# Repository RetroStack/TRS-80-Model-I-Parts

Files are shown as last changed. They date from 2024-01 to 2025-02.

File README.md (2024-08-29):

# TRS-80 Model 1 - Parts

This project includes various items that were part of a TRS-80 Model 1 and have been replicated for 3D printing. Over time, things get lost or break, and this repository was created to provide a way to recover these lost items. The entire project is available under the MIT license.

Below is a list of available items, each with a link to a more detailed description and the STL file. If there is an item missing that you need, see the note at the end of this file.

## Main Enclosure

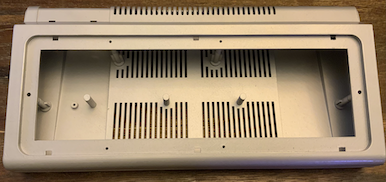
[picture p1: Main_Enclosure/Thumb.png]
Main Enclosure


## Main Enclosure Panel

Main Enclosure Panel

## PCB Stand-Off

PCB Stand-Off

## Keyboard

### Stem (ALPS)

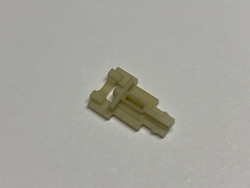
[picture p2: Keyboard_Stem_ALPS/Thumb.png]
Keyboard Stem for ALPS


### Spacebar Clip

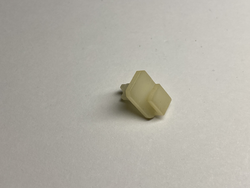
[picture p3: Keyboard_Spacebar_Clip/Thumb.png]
Keyboard Spacebar Clip


### Keyboard Clip

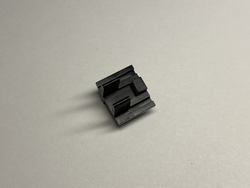
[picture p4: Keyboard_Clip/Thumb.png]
Keyboard Clip


### LED Stand-off

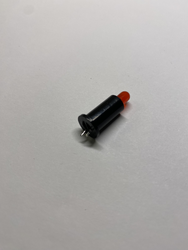
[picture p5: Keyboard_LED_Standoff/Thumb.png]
Keyboard LED Stand-Off


### Button Placeholder (Enter)

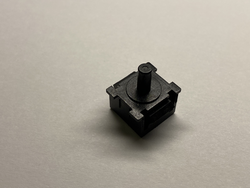
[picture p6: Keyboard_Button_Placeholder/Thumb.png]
Keyboard Button Placeholder (Enter)


### Shield

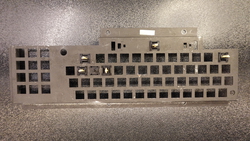
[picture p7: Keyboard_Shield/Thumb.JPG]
Keyboard Shield


### Bezel

Keyboard Bezel

## Extension Interface

### Cover (Medium)

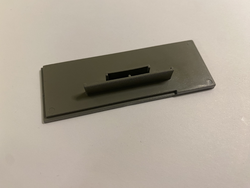
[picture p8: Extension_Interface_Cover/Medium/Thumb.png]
Extension Interface Cover - Medium Size


NOTE: There are three types of covers used: small, medium, and large. I only have the medium, and therefore, only that was digitized.

## External Links

- [Thingiverse - Expansion Interface Port Cover](https://www.thingiverse.com/thing:3330282)
- [Thingiverse - Various port covers](https://www.thingiverse.com/thing:3925677)
- [Thingiverse - Expansion Interface Power Supply Cover](https://www.thingiverse.com/thing:6117675)
- [Thingiverse - Power Supply Case](https://www.thingiverse.com/thing:6273822)
- [Thingiverse - Expansion Interface PCB Case](https://www.thingiverse.com/thing:5742225)
- [Thingiverse - Replacement Screw Post](https://www.thingiverse.com/thing:3202410)
- [Thingiverse - Keyboard Spacer](https://www.thingiverse.com/thing:3764548)
- [Thingiverse - Screw Standoffs Plate](https://www.thingiverse.com/thing:3010034)
- [Thingiverse - Level II Upgrade PCB Mount](https://www.thingiverse.com/thing:3252566)

- [Thingiverse - Mini Model 1](https://www.thingiverse.com/thing:3155677)
- [Thingiverse - Mini Model 2](https://www.thingiverse.com/thing:3497435)
- [Thingiverse - Mini Model 3](https://www.thingiverse.com/thing:4476778)

## Missing Item?

Is an item you are looking for missing in this repo? Feel free to suggest this item to be digitized on my Patreon page (see below).

## Main TRS-80 Model 1 Repository

For additional resources related to the TRS-80 Model 1, be sure to check out the central page for the TRS-80 Model 1 on RetroStack. You can find it [here](https://www.github.com/RetroStack/TRS-80-Model-I).

## Support this Project

RetroStack is passionate about exploring and preserving the legacy of older computer systems. My work involves creating detailed documentation and videos to share the knowledge. I am also dedicated to reviving these classic systems by reimplementing them and offering replacement parts at no cost. If you're keen on supporting this unique project, I invite you to visit my [Patreon page](https://www.patreon.com/RetroStack). Your support would be immensely valuable and greatly appreciated!

## License

This project is licensed under the MIT License - see the [LICENSE](LICENSE) file for details.

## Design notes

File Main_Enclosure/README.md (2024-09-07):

# TRS-80 Model 1 - Main Enclosure - 3D Printer

This page provides three different versions of the TRS-80 Model 1 main enclosure:

- The original, replicating the original case as closely as possible.
- The improved, a main enclosure still compatible with the original but with a few enhancements.
- A mini version for Raspberry Pi emulators.

The first two cases are compatible with the original, fitting nicely on top of each other, and the top and bottom parts can replace broken parts of the original case.

Here is a comparison of a painted replica to an original case:

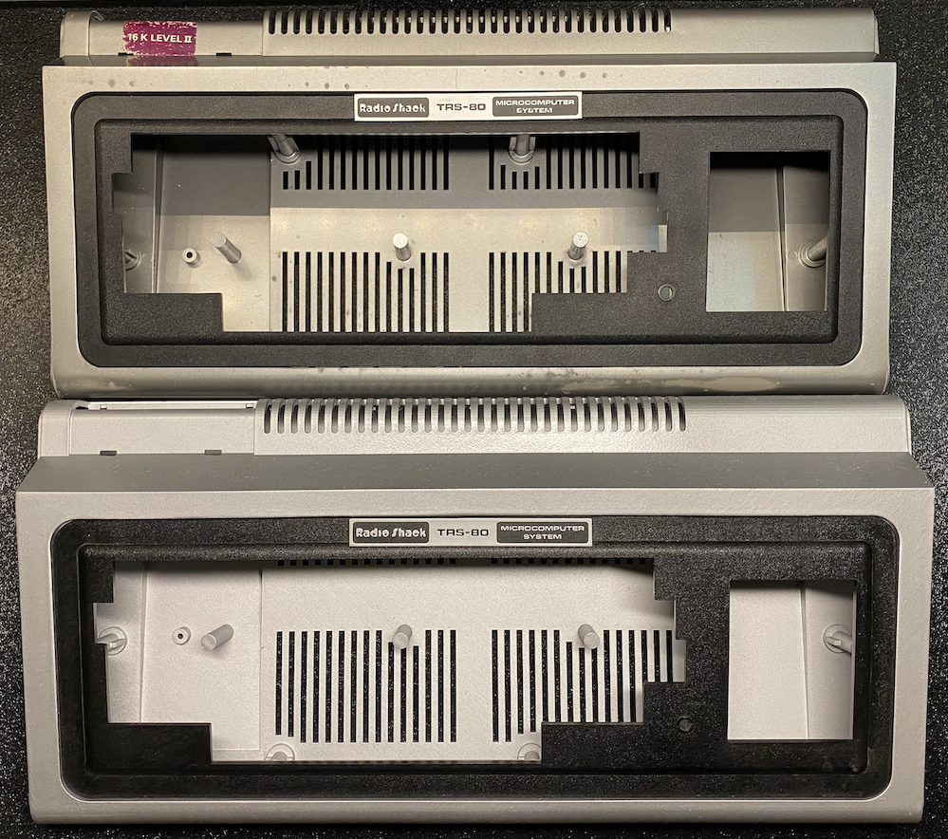
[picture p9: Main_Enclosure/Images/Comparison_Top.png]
Top

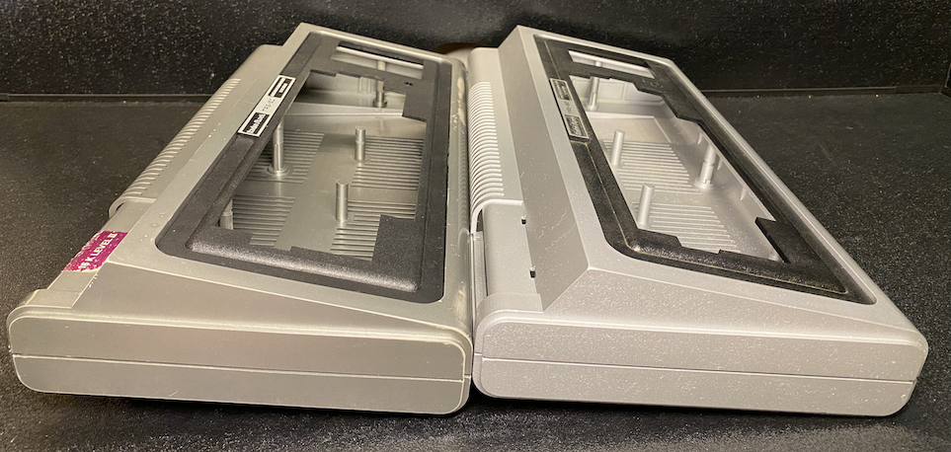
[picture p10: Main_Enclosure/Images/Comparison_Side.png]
Side

Bottom

## The Original

A fully painted case after printing:
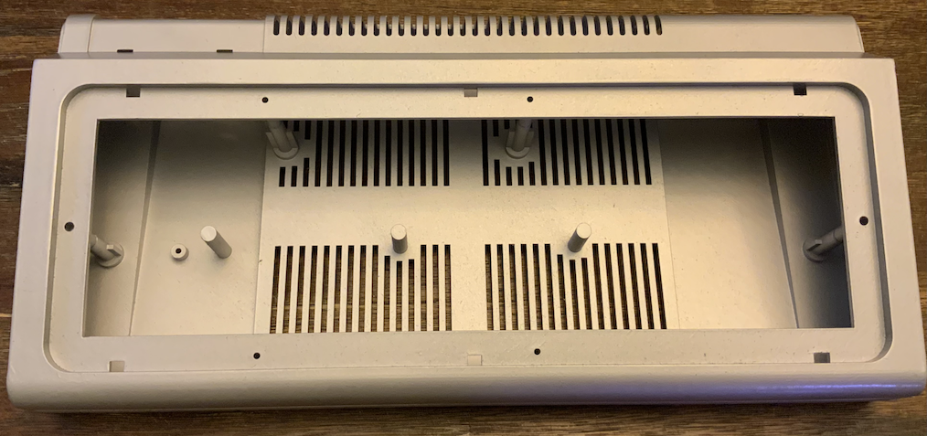
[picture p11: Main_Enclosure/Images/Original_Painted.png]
Original Painted


A cross-section of the case:
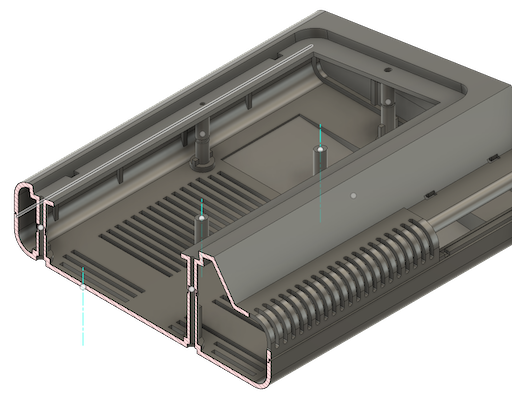
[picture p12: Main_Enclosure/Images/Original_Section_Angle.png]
Original Cross Section


There are two versions of this:

- A full STL of both the upper and lower parts
- A split version with parts no larger than 216mm x 205mm to fit many home 3D printers (scroll down)

### STL

The following files are available in STL format:

- [STL (Top)](Original_Top.stl)
- [STL (Bottom)](Original_Bottom.stl)

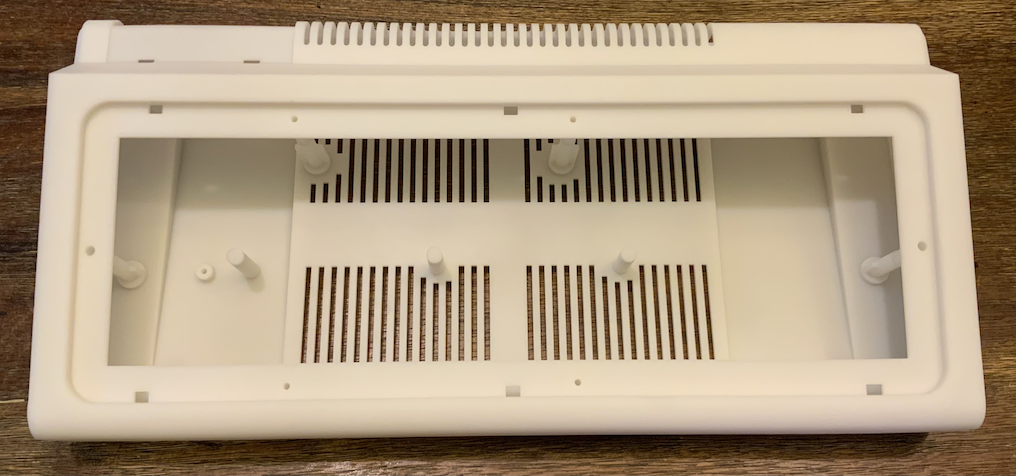
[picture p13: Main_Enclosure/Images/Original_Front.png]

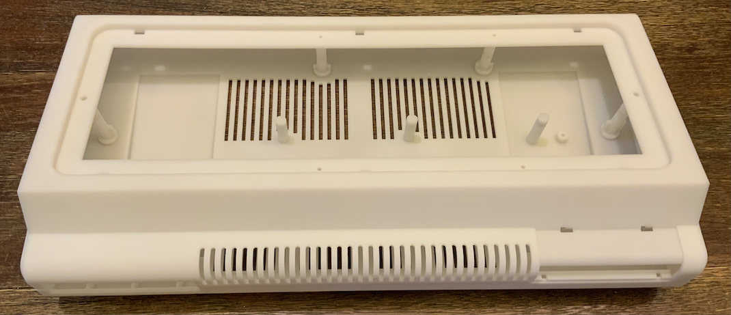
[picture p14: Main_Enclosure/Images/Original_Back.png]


### Print Instructions

You can print them yourself, but most likely you do not have such a large printer. You can order them online. What follows are instructions for JLC3DP, which I've had good experiences with. Additionally, they take care of sanding and finishing.

- Go to [JLC3DP](https://www.jlcpcb.com).
- Click the "Quote Now" button under the "3D Printing" image.
- Click the "Add 3D file" and select the STL file provided above.

A few options appear. I always selected "SLA(Resin)" for the technology, which has a very smooth surface.

The default selection of "LEDO 6060 Resin" is what I've used for the case. It is also the more affortable option.

Leave all other options as-is.

You still have to select a "Product Description". Apparently, this is some customs requirement. I've selected "Office Appliances and Accessories" and "Keyboard Enclosure" in the past.

You can then hit "Save to Cart" and checkout.

By default, they will review your designs and send you an email to pay within a few hours. Simply go back to your order page (after you've created an account) and select "Pay".

NOTE: Most of the time, however, they will also send you an email to confirm that you want to assume the risk of ordering the design as-is as they are too long and may deform during production or have parts which are too thin. I've always accepted the risk and never had any trouble.

### 3D Printer friendly STL

This 3D printer-friendly version of the file is divided into parts no larger than 216mm x 205mm. Each part can be clipped into the other. Additionally, there is a small gap available for glue to permanently affix the case parts together.

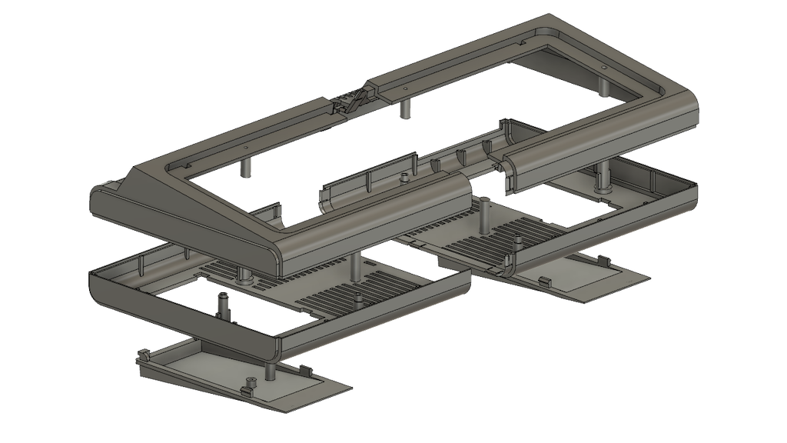
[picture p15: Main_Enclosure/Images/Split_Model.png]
Split Case


- [STL (Top-Left)](Top_Left.stl)
- [STL (Bottom-Left)](Bottom_Left.stl)
- [STL (Bottom-Left-Foot)](Bottom_Left_Foot.stl)
- [STL (Top-Right)](Top_Right.stl)
- [STL (Bottom-Right)](Bottom_Right.stl)
- [STL (Bottom-Right-Foot)](Bottom_Right_Foot.stl)

#### Case Parts

The top and bottom are split, and each side can be clipped into the other.

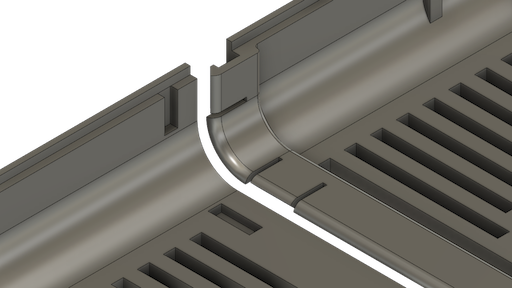
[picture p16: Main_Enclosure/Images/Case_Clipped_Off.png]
Unclipped Case

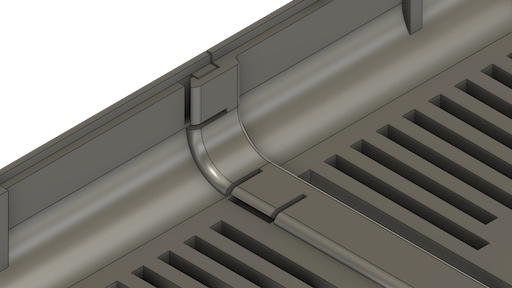
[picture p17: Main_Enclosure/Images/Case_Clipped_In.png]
Clipped Case


#### Foot Parts

The feet can be clipped in by pivoting them into place and then clipping in the other side. Separating the feet will reduce unnecessary support.

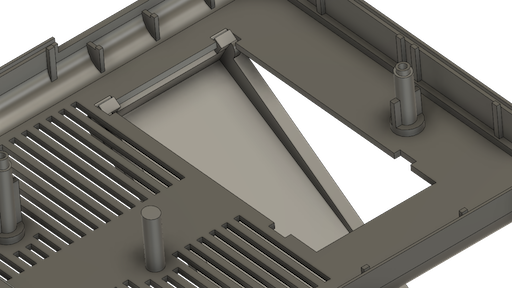
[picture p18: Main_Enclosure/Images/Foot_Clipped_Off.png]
Unclipped Foot

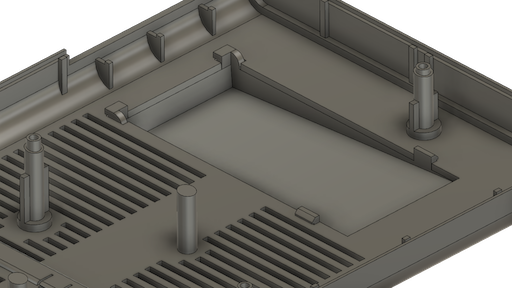
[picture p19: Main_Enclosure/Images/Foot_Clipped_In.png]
Clipped Foot


The top and bottom halves can be screwed together like the original case. 

## The Improved

A fully painted case after printing:
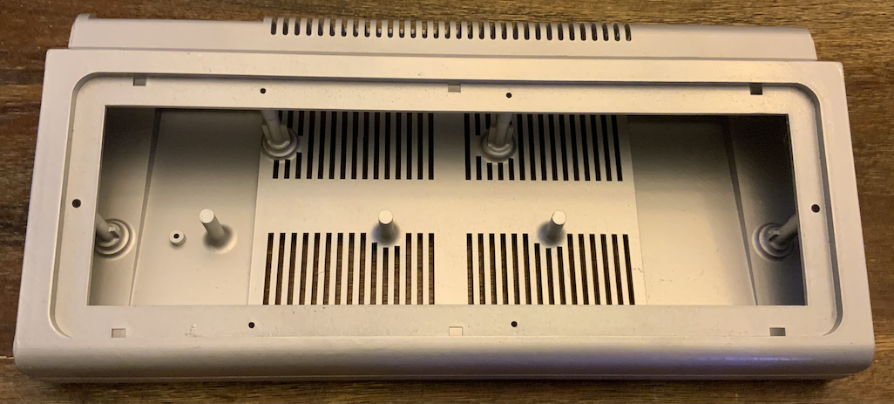
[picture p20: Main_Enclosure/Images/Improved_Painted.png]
Improved Painted


A cross-section of the case:
Original Cross Section

### Differences to Original

There are a few differences.

To help show these differences, here is a cross-section of the original and the improved versions:
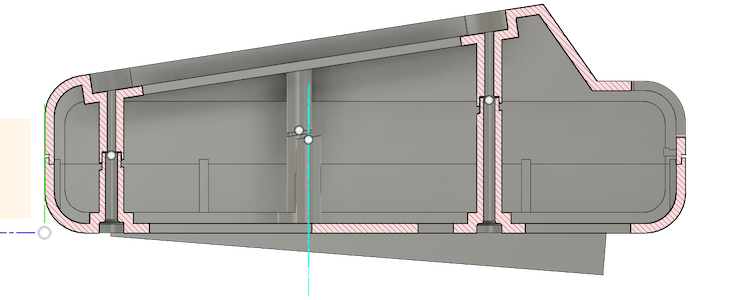
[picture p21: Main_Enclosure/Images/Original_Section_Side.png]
Original

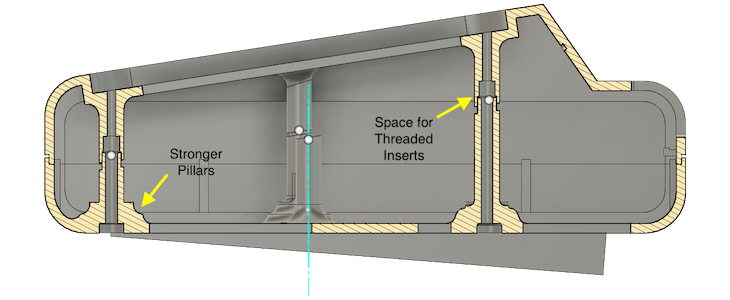
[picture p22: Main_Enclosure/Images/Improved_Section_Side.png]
Improved


The internal pillars that hold the PCB and keyboard in place, and their additional function of keeping the case together through screws, easily break off in the original. The new improved version has a much wider base to avoid breaking at the base of these pillars, addressing a common issue for the top and bottom of the case.

After opening the case a few times, the threads created by the self-threading screws in the old plastic are stripped and won't hold the case together anymore. To avoid this problem altogether, the improved case now has the (optional) ability to add knurled threaded inserts.

There are additional changes:

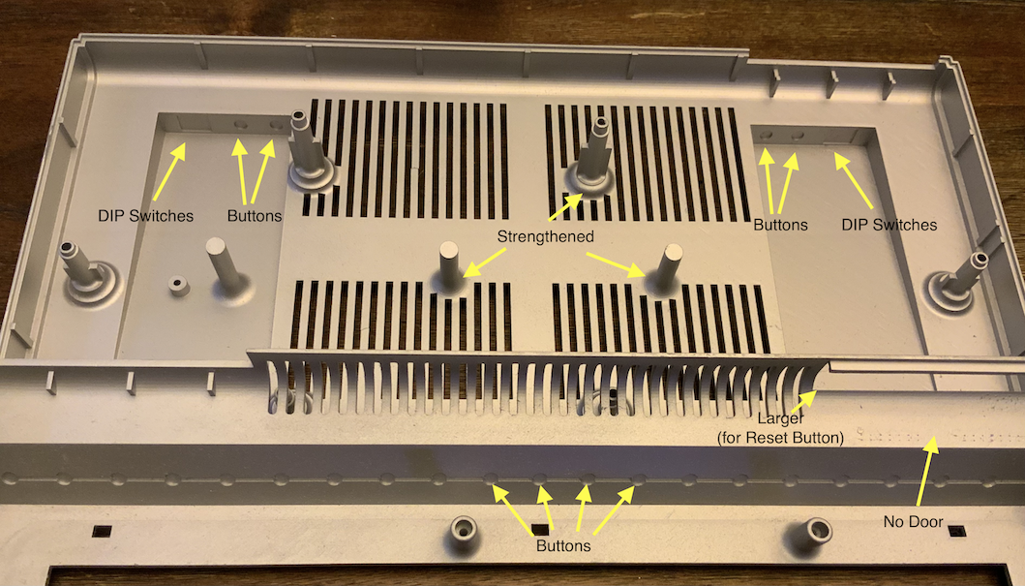
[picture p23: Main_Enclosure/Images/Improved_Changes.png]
Changes


- Provides perforated areas for DIP switches, potentiometers, and buttons in the top and base of the case.
- The opening in the back has been slightly enlarged to make it easier to access the reset button.
- The door on the back, which is missing in nearly all cases nowadays, was completely removed.

Many of these improvements were suggested by various people, including Amar, Scott, and Ven.

### STL

The following files are available in STL format:

- [STL (Top)](Improved_Top.stl)
- [STL (Bottom)](Improved_Bottom.stl)

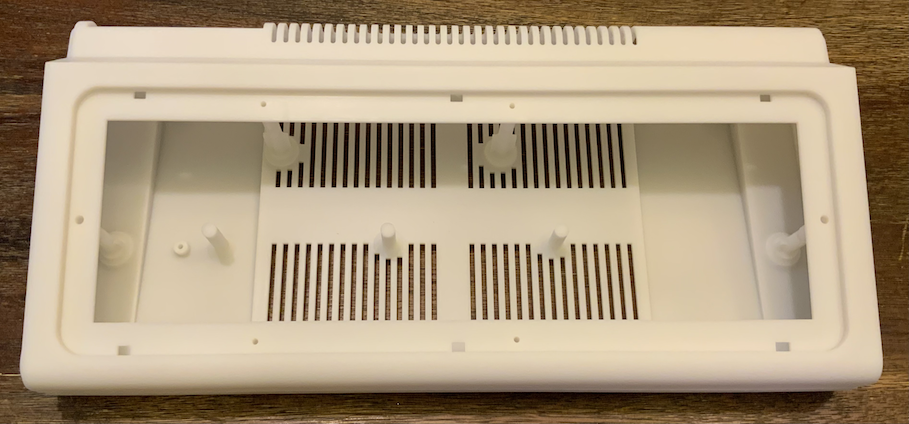
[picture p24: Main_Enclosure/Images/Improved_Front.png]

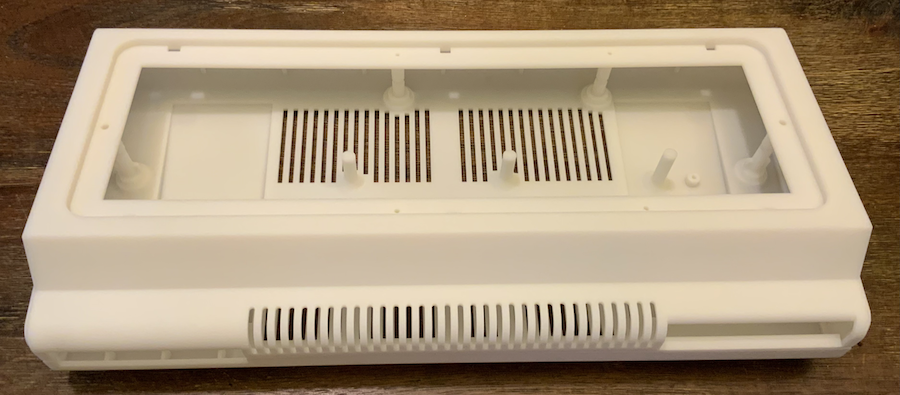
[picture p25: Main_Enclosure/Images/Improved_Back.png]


### Print Instructions

Use the same print instructions as the original case above.

## Mini Case

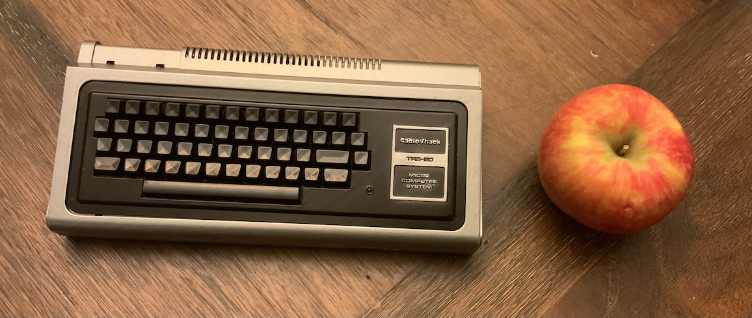
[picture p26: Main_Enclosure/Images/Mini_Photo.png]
Model 1 Mini


A compact version designed to hold an emulator without cluttering your desk space can be appealing to some. This case is specifically tailored for Raspberry Pi emulators. It features convenient front access to the SD card and a widened opening at the back, where the edge connector would typically be, allowing easy access to all USB ports.

The case is compatible with Raspberry Pi version 1-3 and Raspberry Pi W. It is not compatible with the latest version 4.

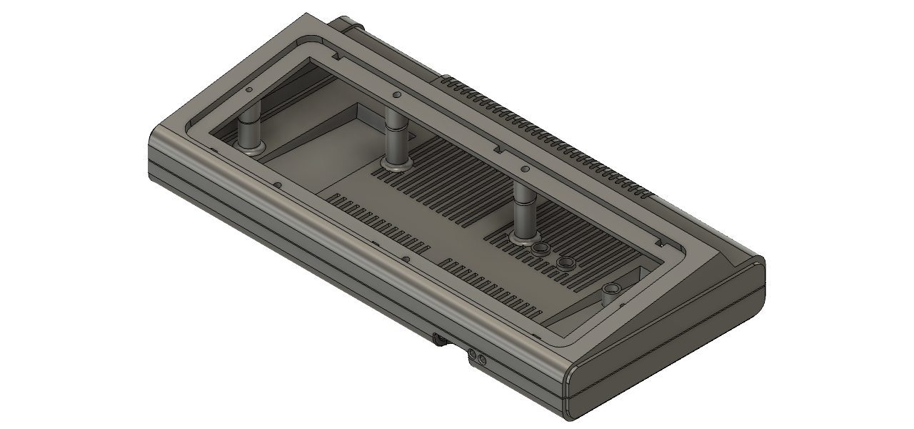
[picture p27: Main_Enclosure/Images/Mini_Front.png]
Model 1 Mini

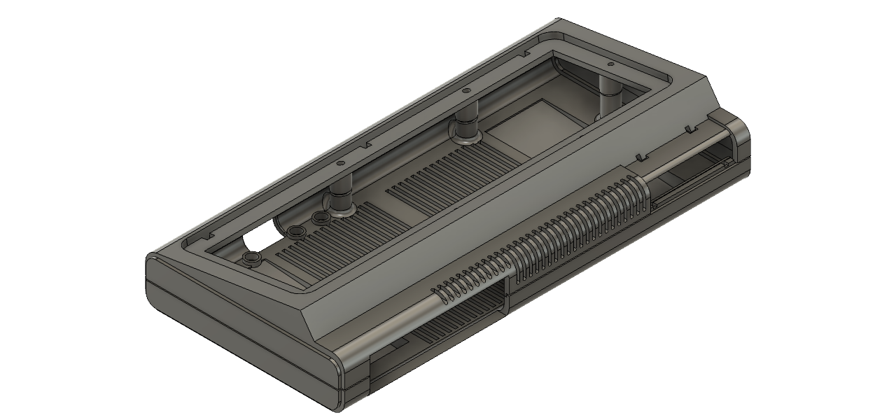
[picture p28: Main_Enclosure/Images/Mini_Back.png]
Model 1 Mini

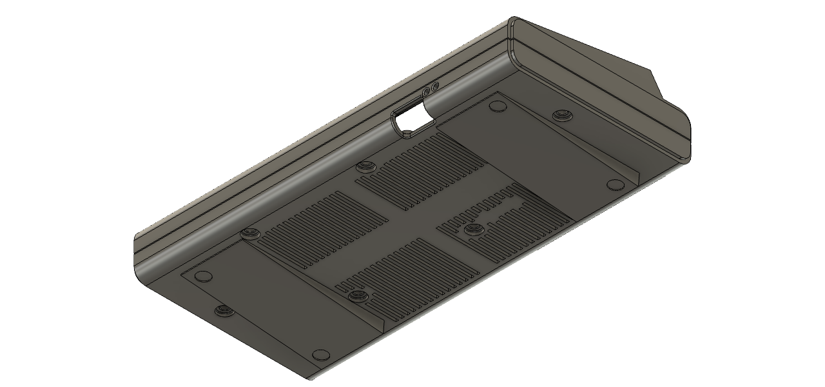
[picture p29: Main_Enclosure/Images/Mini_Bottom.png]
Model 1 Mini


Here is a quick comparison of the sizes of all three cases mentioned on this page:

Size Comparison

The case also includes a custom Bezel that emulates the original keyboard:

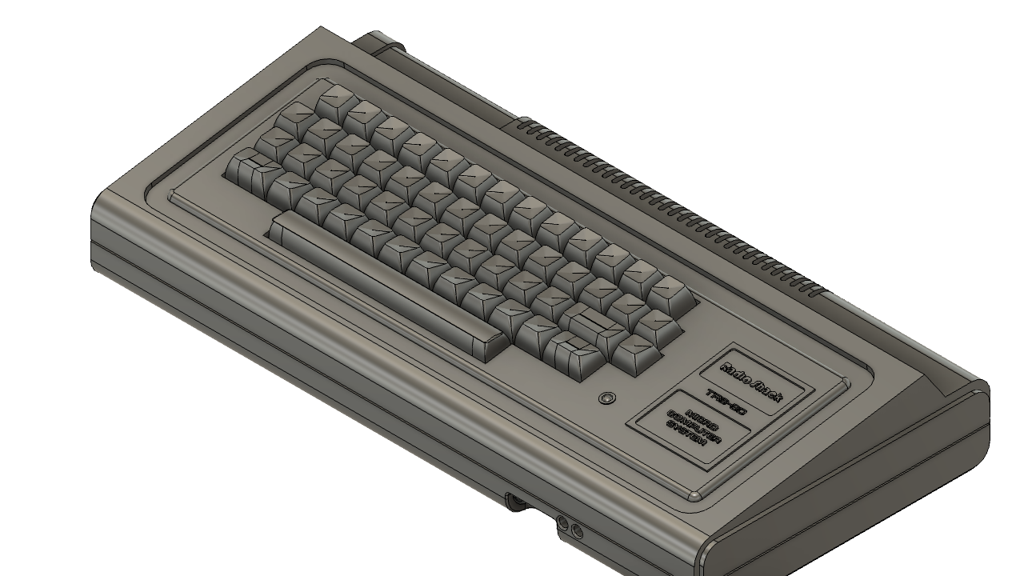
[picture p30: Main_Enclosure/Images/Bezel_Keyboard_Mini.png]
Mini Bezel


### STL

- [STL (Top)](Top_Mini.stl)
- [STL (Bottom)](Bottom_Mini.stl)
- [STL (Bezel)](Bezel_Alpha_Original_Keys_Mini.stl)

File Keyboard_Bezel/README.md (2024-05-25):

# TRS-80 Model 1 - Keyboard Bezel

The keyboard bezel covers the keyboard and closes up the case in the front.

**NOTE**: If you are looking for the Bezels of the MX Keyboard with the smaller spacebar, then please go to the [MX Keyboard repo](https://github.com/RetroStack/TRS-80-Model-I-Keyboard-MX) instead.

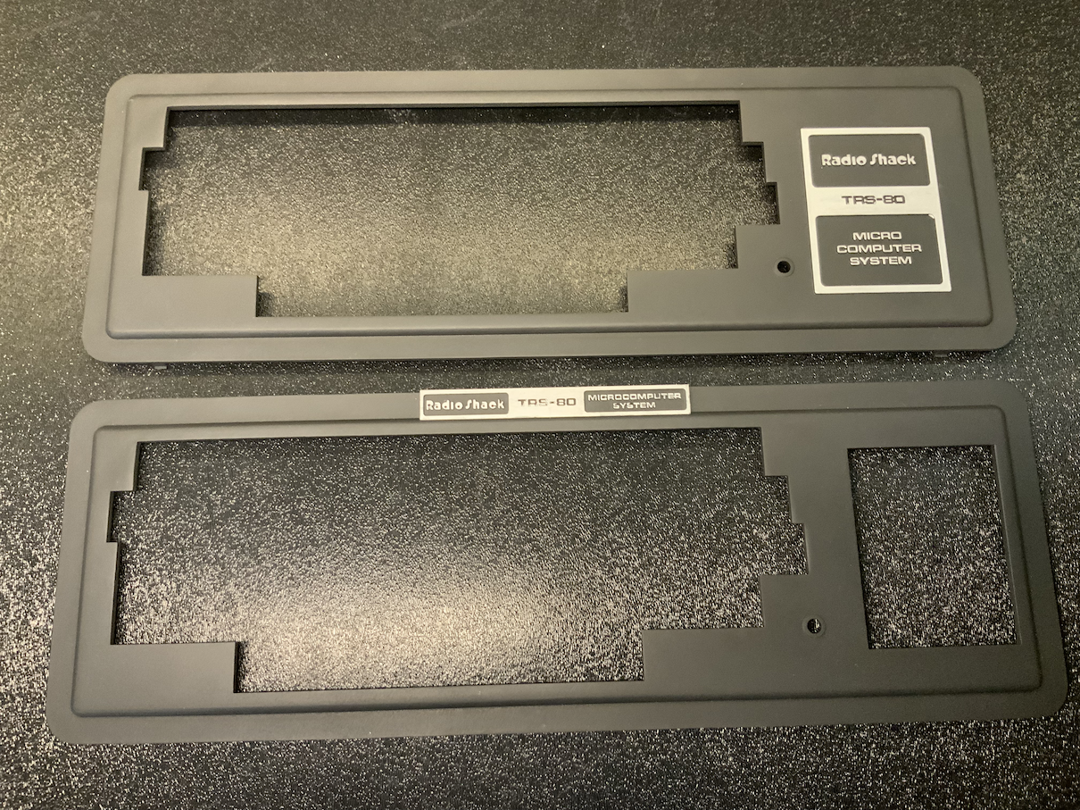
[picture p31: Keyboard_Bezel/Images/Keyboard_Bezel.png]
View


## STL

Following designs are available in STL format:

- [Full keyboard with Numpad](Bezel_NumPad_Original.stl)
- [Keyboard without the Numpad](Bezel_Alpha_Original.stl)

## Order Instruction - [JLC3DP](https://www.jlcpcb.com) (service of JLCPCB)

You can print them yourself, but most likely you do not have such a large printer. You can order them online. What follows are instructions for JLC3DP, which I've had good experiences with. Additionally, they take care of sanding and finishing.

- Go to [JLC3DP](https://www.jlcpcb.com).
- Click the "Quote Now" button under the "3D Printing" image.
- Click the "Add 3D file" and select the STL file provided above.

A few options appear. In either case, I always selected "SLA(Resin)" for the technology, which has a very smooth surface.

For the bezel, I would choose the "Black Resin" option. It is a bit more expensive than the default, but it will reduce post-processing for you as you probably do not want a white bezel.

Leave all other options as-is.

You still have to select a "Product Description". Apparently, this is some customs requirement. I've selected for both "Office Appliances and Accessories" and "Keyboard Enclosure".

You can then hit "Save to Cart" and checkout.

By default, they will review your designs and send you an email to pay within a few hours. Simply go back to your order page (after you've created an account) and select "Pay".

NOTE: Most of the time, however, they will also send you an email to confirm that you want to assume the risk of ordering the design as-is as they are too long and may deform during production or have parts which are too thin. I've always accepted the risk and never had any trouble.

## Use Cases

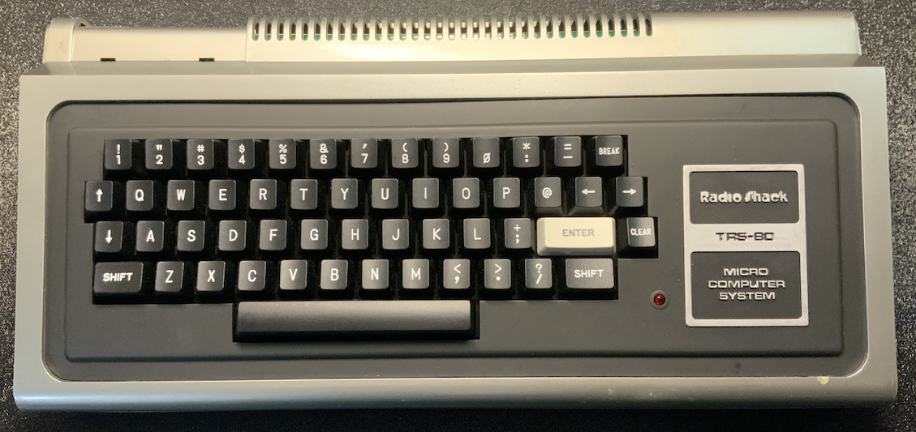
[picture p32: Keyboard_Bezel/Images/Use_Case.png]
Assembled


## Special STL

This special bezel can fill the hole of a broken keyboard, using a USB keyboard instead.

In STL format:

- [Keyboard Bezel](Bezel_Alpha_Original_Keys.stl)

Keyboard Bezel

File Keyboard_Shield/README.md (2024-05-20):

# TRS-80 Model 1 - Keyboard Shield (for ALPS Keyboard)

The keyboard shield has a few functions:

- Protects the keyboard PCB and mainboard PCB from external factors.
- Keeps the keycaps at a specified place and distance to the case.
- Separates the keyboard PCB from the main PCB

View 1
View 2

**NOTE**: If you are looking for the Shield of the MX Keyboard with the longer sides, then please go to the [MX Keyboard repo](https://github.com/RetroStack/TRS-80-Model-I-Keyboard-MX) instead.

## STEP

This is a sheet metal version of the keyboard shield replica. You can use the STEP file to submit it to online sheet metal fabs like SendCutSend, Fabworks, or PCBWay.

[STEP](Keyboard_Shield_ALPS_v2.step)

Configuration:

- Suggested Material: Steel G90 (SendCutSend), Steel 1008 (Fabworks)
- Thickness: 1.22mm (0.048")
- K Factor: 0.46
- Bend Radius: 0.762
- Finish: Matte Black

## Order Instructions - [Fabworks](https://www.fabworks.com)

Go to [Fabworks](https://www.fabworks.com) and drop the [STEP file](/Latest/TRS80_Model_I_Keyboard_MX_E2_Shield.step) into the upload section (or select it by clicking it).

This will open up a new page and show a small preview of the shield.

- Select the material "Steel 1008".
- Set thickness to 0.048" or 1.22mm.
- Select "Matte Black" as finish.
- (optionally) Modify the quantity

Click on "Checkout".

NOTE: The original shield has a thickness of 1.5mm. However, if you select 1.5mm and the paint of the finish is added, the thickness will increase, and the key switches won't fit anymore (or at least will not click in). Additionally, the design is for 1.22mm. Changing the thickness to another value will change the position of the mounting holes slightly. Small variations, however, should not be problematic.

## Use Cases

Top
Bottom

### Assembled

Top
Bottom

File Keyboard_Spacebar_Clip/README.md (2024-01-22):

# TRS-80 Model 1 - Keyboard Spacebar Clip - 3D Printer

The spacebar clip holds the small metal bar in place to ensure consistent pressure on the button across the spacebar keycap. It also helps to reduce pivoting, thereby decreasing the overall stress on the keycap pin. 

See the assembly instructions below.

Unfortunately, the metal rod is easily lost. Below is also a description of how to recreate the metal rod.

## STL

View 1
View 2

[STL](Keyboard_Spacebar_Clip.stl)

## 3D Printer-Friendly STL

View 1
View 2

[STL](Keyboard_Spacebar_Clip_Printable.stl)

### Print Instructions

- Lay the clip on either of its longer sides.
- Add support for the cross pin and the clip. The support at the cross pin will need to be removed afterward.

Print

## Use Cases

Uses

### Profile 

Bottom
Profile
Front
Side

### Assembled

Assembled

### Assembly

Step 1

1. Insert the cross pin on the back into either side of the spacebar keycap. Ensure you position the clip towards the top of the spacebar keycap, as the keycap is more slanted at the top than at the bottom.

Step 2

2. Press firmly on the largest flat areas of the clip on either side. Do not press on the clip itself, as it may crack from the pressure.

## Metal Rod

Rod

1. Cut a 1.6mm rod to a length of 152mm.
2. Make marks with a pencil on the rod on either side at 16mm and 10mm.
3. Bend one end of the rod at the 10mm mark 90 degrees, in any direction. Ideally, use a heavy-duty needle nose plier and bend just right before the mark. That way the bend will extend beyond the 10mm mark as expected with the measurement. The bend starts at 10mm.
4. Bend the next 90 degrees back in the same direction the rod was originally heading at the 16mm mark. Do the same as bfore: start bending it right before the mark.
5. Repeat steps 2 and 3 for the other side as well, but make sure the rod stays flat overall. The central part of the metal rod will have a length of about 120 mm.

**Note**: Ensure that the metal rod lies somewhat flat when placed on a table. You can twist the bends slightly to correct their direction, making them flat.

## Changelog

### 21st Jan 2024

- Updates to metal rod section: more accurate numbers and photo of result.
- Addition of chamfer to model to closely resemble original
- Addition of printable version: clip sides are flattened to read bed

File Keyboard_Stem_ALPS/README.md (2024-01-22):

# TRS-80 Model 1 - Keyboard Stem (for ALPS Keyboard) - 3D Printer

The stem transfers the force from a finger press on the keycap to the spring and simultaneously presses the metal flap inside the button, creating the contact needed for the button press to be recognized. These components easily break and often require replacement.

See the assembly and disassembly instructions below.

## STL

View 1
View 2

[STL](Keyboard_Stem_ALPS.stl)

## 3D Printer-Friendly STL

View 1
View 2

[STL](Keyboard_Stem_ALPS_Printable.stl)

### Print Instructions

- Lay the stem flat on the bed, ensuring the very flat side is at the bottom.
- Add support for the small pin for the spring. This support will need to be removed afterward for it to function properly.

Print

## Use Cases

Top
Bottom

### Assembled

Top
Bottom
Back

### Disassembled

Disassembled

### Disassembly

1. Use something thin and long that can go between the plastic flaps on each side of the casing. In this case, I've used an electronics tweezer. 

Step 1
Step 2

2. Push further in to spread the plastic flaps away from the bottom part of the case.

Step 3

3. Pull up on the top part of the case, separating the parts and freeing the stem. Be careful not to lose the spring, as it may shoot out during the process.

Step 4

### Assembly

Step 1

1. Insert the spring into the casing.
2. Pivot the casing forward so that the spring leans against the front of the casing.
3. Add the stem with the "pin" side down. The spring should be around the pin. Do not press down on the spring, as the stem will shoot out again as soon as you let go. Simply rest it on the spring.

Step 2

4. Get the top part of the cover. Make sure to orient the T-hole as shown.
5. Fit the stem through the hole and gently press together until the flaps click in.

Step 3

## Changelog

### 21st Jan 2024

- Thinning of stem: needed filing to not get stuck

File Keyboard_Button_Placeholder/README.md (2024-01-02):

# TRS-80 Model 1 - Keyboard Button Placeholder - 3D Printer

The placeholder is used to guide the Enter key straight down as the ALPS key is located on the other side of the 2x size key. Without it, the key will create too much strain on the Enter-key stem and break it.

See the assembly instructions below.

## STL

View 1
View 2

[STL](Keyboard_Button_Placeholder.stl)

## 3D Printer-Friendly STL

View 1
View 2

[STL](Keyboard_Button_Placeholder_Printable.stl)

### Print Instructions

- Lay the item on its side with the closed side of the box on the bed. The opening should be towards the top.
- Add support for the pin. This support will need to be removed afterward for it to function properly.

Print

**NOTE**: The real item has also clips, but it isn't necessary as the stem will keep this item in place.

## Use Cases

In Keyboard Shield
Keyboard Location

### Profile

Angle
Back
Side
Top

### Assembly

Location on the keyboard:

Location

Notice that the Enter Keycap has one side the has a round hole.

Step 1

The other side of the keycap will house the cross stem.

Step 2

With both fitted, it will look like the following. This is ony to demonstrate where each goes. Don't assemble already.

Step 3
Step 4

When the item is put into the shield, you can simply clip the keycap on top of it. This only works if the ALPS key is oriented correctly (see above image).

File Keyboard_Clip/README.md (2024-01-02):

# TRS-80 Model 1 - Keyboard Clip - 3D Printer

The clip is attached to the keyboard shield and holds the spacebar rod fixed to the keyboard shield. This is the counter part to the Keyboard Spacebar clips.

See the assembly and disassembly instructions below.

If you are missing the spacebar rod, then please check the instructions on how to create a new one in the Keyboard Spacebar clips page.

## STL

View 1
View 2

[STL](Keyboard_Clip.stl)

## 3D Printer-Friendly STL

View 1
View 2

[STL](Keyboard_Clip_Printable.stl)

### Print Instructions

- Lay the item on its side where the clip touches the bed. The two flaps should be on the top.
- Add support for the two flaps. This support will need to be removed afterwards to make sure the clip fits in the holes.

Print

## Use Cases

In Keyboard Shield
Removed from Shield
On Rod
Both on Rod

### Profile

Top
Top
Top
Top
Top
Top

### Assembled

Assembled

### Disassembly

Simply press the two flaps together and push it out. You can also use something small (round-ish) to push against the square plastic tab.

### Assembly

- Feed the item from the top into the keyboard shield. Both go in the same orientation on either side of the keyboard spacebar.
- Make sure the square tab is oriented with the hole.
- Keep pushing in until the two flabs click in place.

**NOTE**: The square tab is there to ensure orientation. Make sure to lower it straight down.

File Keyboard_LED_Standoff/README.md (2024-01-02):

# TRS-80 Model 1 - Keyboard LED Stand-Off - 3D Printer

The LED Stand-off gives rigidity to the LED on the keyboard PCB. It also makes sure that the LED easily fits into the casing hole at the keyboard.

See the assembly instructions below.

## STL

View 1
View 2

[STL](Keyboard_LED_Standoff.stl)

### Print Instructions

Stand the item up with the wide side at the bottom. In the center, there is a small separater for the LED legs and therefore the items needs to be printed in that orientation.

Print

## Use Cases
ß
In PCB

### Profile
Top
Bottom

### Assembly

**NOTE**: Use a 5mm LED!

Step 1

1. The top hole has one side with a straight edge. That is where the flat side of the LED head sits. The round parts should snugly fit into the hole and rest on the ring inside.
2. When pushing the LED all the way through, make sure the legs are separated into each side of the split in the tube.

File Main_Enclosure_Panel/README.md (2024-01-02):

# TRS-80 Model 1 - Main Enclosure Panel - 3D Printer

The Main Enclosure Panel is used to cover an opening at the back of the computer, protecting the main PCB. It also provides access holes and labels for power, video, and tape interfaces, as well as a hole for the power button.

## STL

View 1
View 2

[STL](Main_Enclosure_Panel.stl)

## 3D Printer-Friendly STL

View 1
View 2

[STL](Main_Enclosure_Panel_Printable.stl)

### Print Instructions

- Lay the panel flat on the bed, label-side up.
- Add support at the bottom.

Print

**Note**: The writing is very thin, and many printers may not be able to print it!

## Use Cases

In Place
Front
Back

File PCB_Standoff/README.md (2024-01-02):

# TRS-80 Model 1 - PCB Stand-off - 3D Printer

The PCB standoff is being used to separate the keyboard from the mainboard to avoid electronic connectivity. Additionally, since it is made of gummy like material, it buffers each keystroke on the keyboard a bit, reducing the stress on the mainboard.

## STL

View 1

[STL](PCB_Standoff.stl)

## Print Instructions

Print the item with either flat side down. This ensures that the standoff is round, although this isn't strictly necessary.

Make sure you use a flexible filament, such as NinjaFlex or another type of TPU. The flexibility is necessary for dampening each keystroke. Printing it in plastic might actually end up damaging the main PCB board.

Print

## Use Cases

Buffering and Positioning
Distribution across PCB
By Itself

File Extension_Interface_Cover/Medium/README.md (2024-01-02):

# TRS-80 Model 1 - Extension Interface Cover (Medium) - 3D Printer

These covers are for the Extension interface, covering up holes in the casing to block access to the edge-connectors and PCB. These covers are mostly cosmetic, but also protect the edge-connectors.

## STL

View 1
View 2

[STL](Extension_Interface_Cover_Medium.stl)

## 3D Printer-Friendly STL

View 1
View 2

[STL](Extension_Interface_Cover_Medium_Printable.stl)

### Print Instructions

- Lay the cover flat on the bed.
- No need for any support.

Print

## Use Cases

Assembled
Open

### Profile

Top 1
Top 2

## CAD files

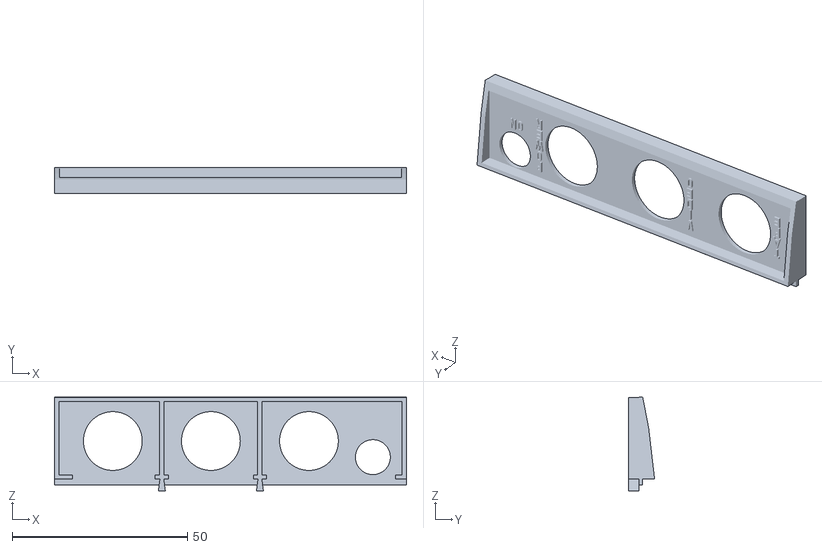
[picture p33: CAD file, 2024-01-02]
Main_Enclosure_Panel/Main_Enclosure_Panel_Printable.stl
100.5 x 7.49 x 26.7

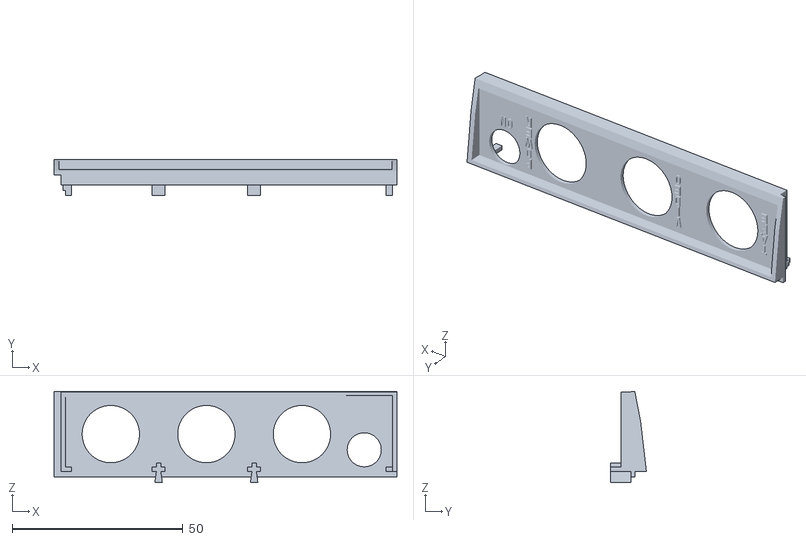
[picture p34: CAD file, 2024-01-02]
Main_Enclosure_Panel/Main_Enclosure_Panel.stl
100.5 x 10.5 x 26.7

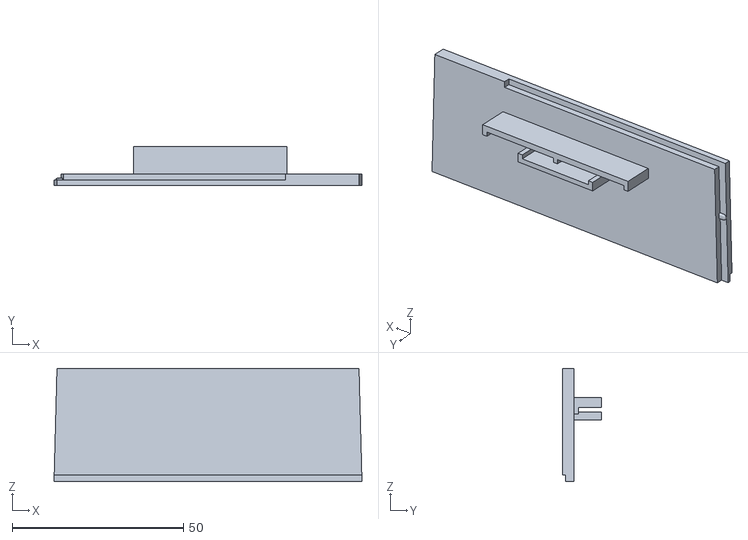
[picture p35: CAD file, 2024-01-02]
Extension_Interface_Cover/Medium/Extension_Interface_Cover_Medium.stl
90.0 x 11.3 x 33.2

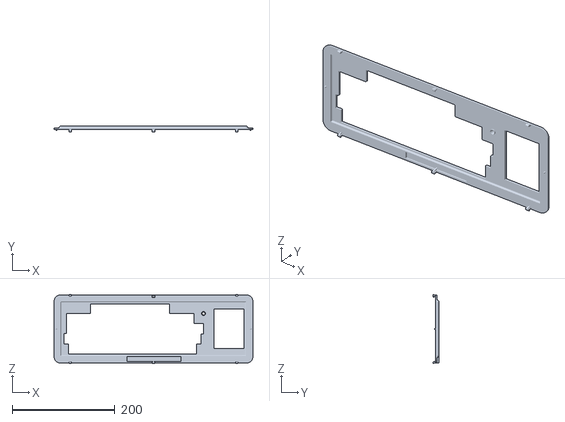
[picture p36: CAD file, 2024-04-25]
Keyboard_Bezel/Bezel_NumPad_Original.stl
388.0 x 12.5 x 135.5

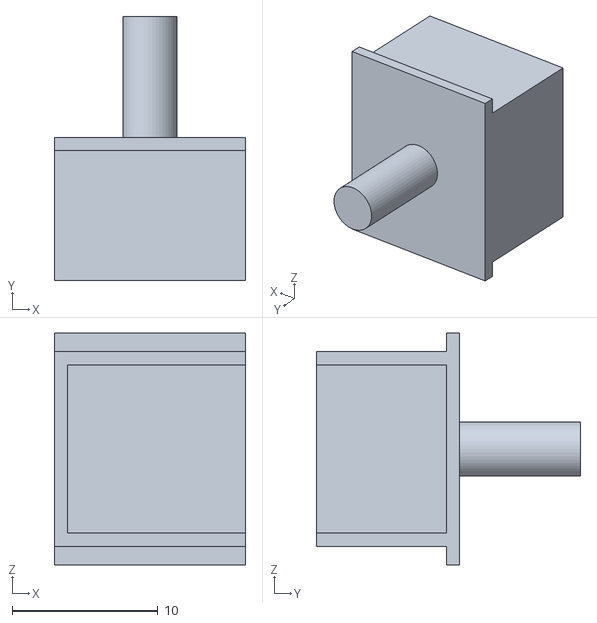
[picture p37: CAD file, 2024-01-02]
Keyboard_Button_Placeholder/Keyboard_Button_Placeholder_Printable.stl
13.1 x 18.1 x 15.9

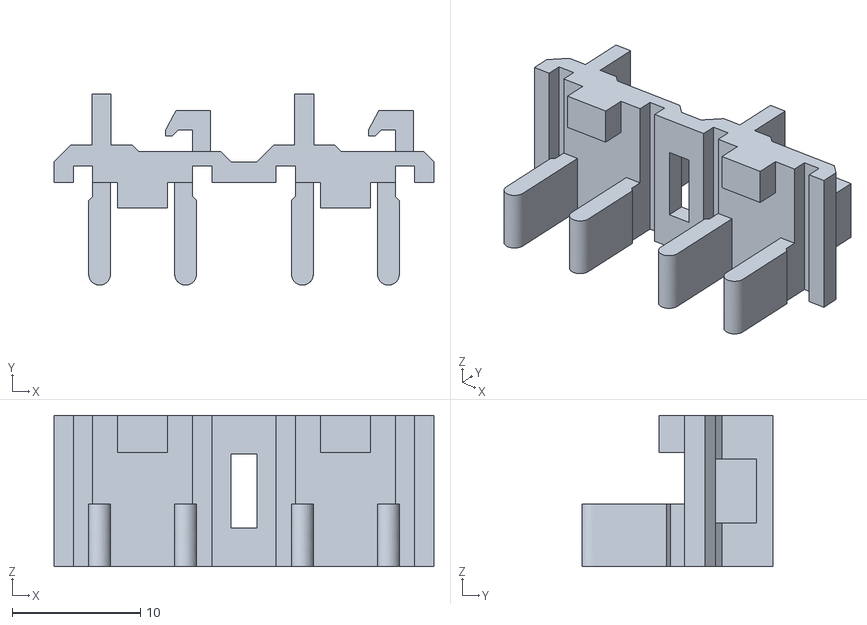
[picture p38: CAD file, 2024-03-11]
Keyboard_Clip/Keyboard_Clip_Dual.stl
29.6 x 14.9 x 11.8

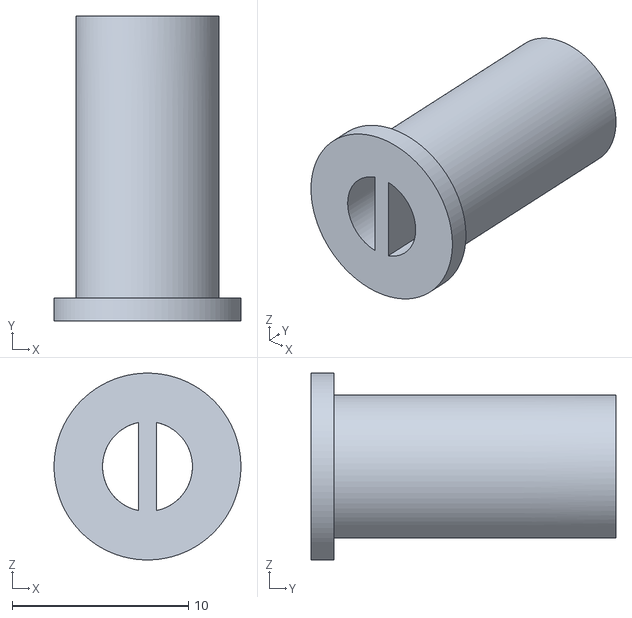
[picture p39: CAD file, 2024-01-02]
Keyboard_LED_Standoff/Keyboard_LED_Standoff.stl
10.6 x 17.3 x 10.6

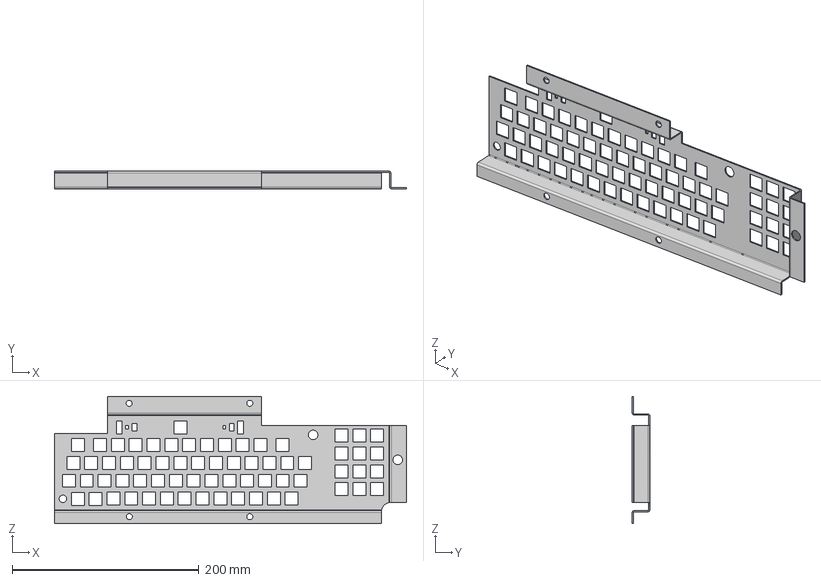
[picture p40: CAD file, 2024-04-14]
Keyboard_Shield/Keyboard_Shield_ALPS_v2.step
377.3 x 19.0 x 136.6 mm

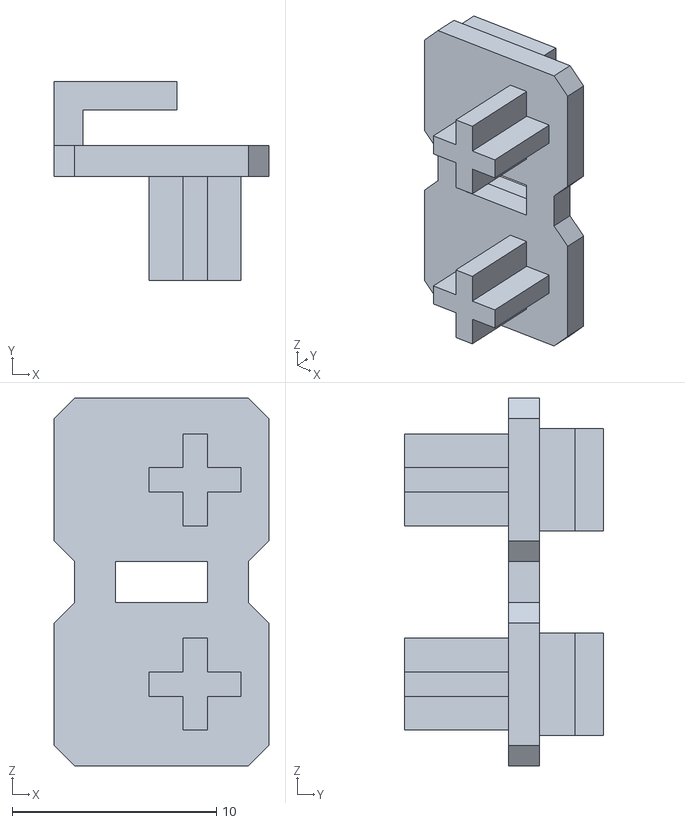
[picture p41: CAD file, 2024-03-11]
Keyboard_Spacebar_Clip/Keyboard_Spacebar_Clip_Dual.stl
10.5 x 9.75 x 18.0

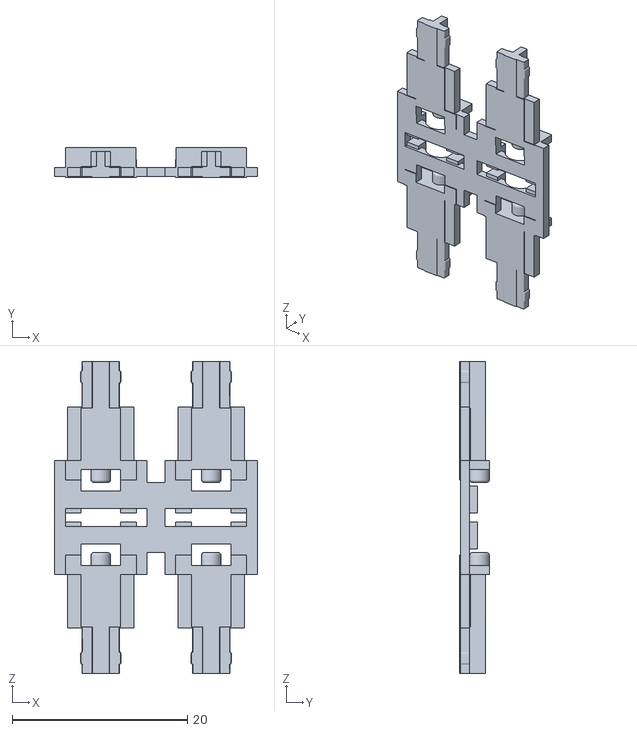
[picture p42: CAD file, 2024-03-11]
Keyboard_Stem_ALPS/Keyboard_Stem_ALPS_Quad.stl
23.2 x 3.40 x 35.6

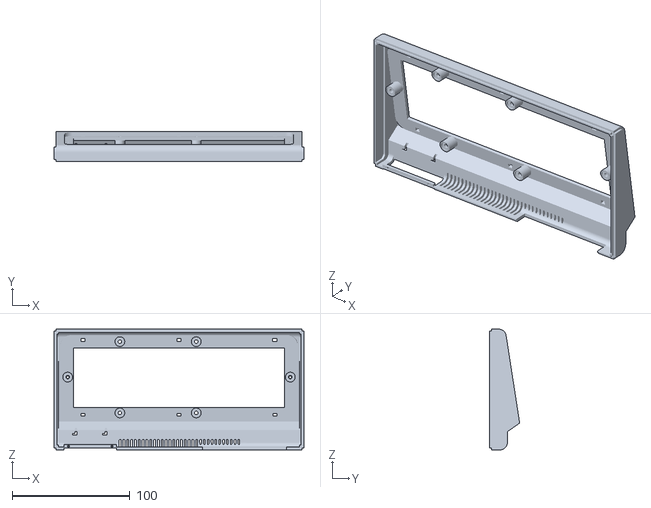
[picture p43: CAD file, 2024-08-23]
Main_Enclosure/Top_Mini.stl
212.0 x 25.8 x 102.5

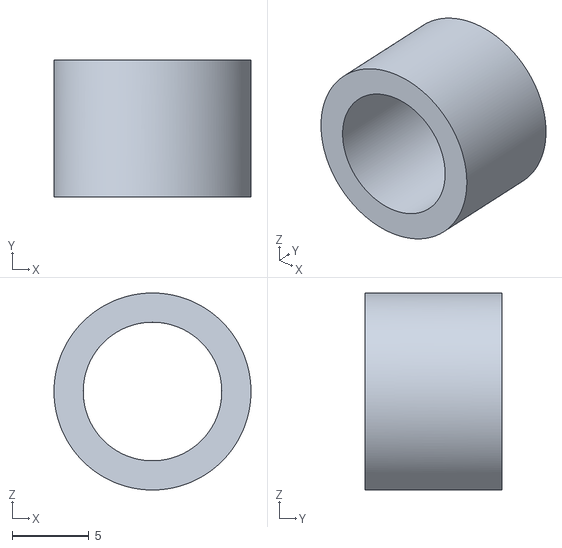
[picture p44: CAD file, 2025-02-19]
PCB_Standoff/PCB_Standoff.stl
12.8 x 8.90 x 12.8

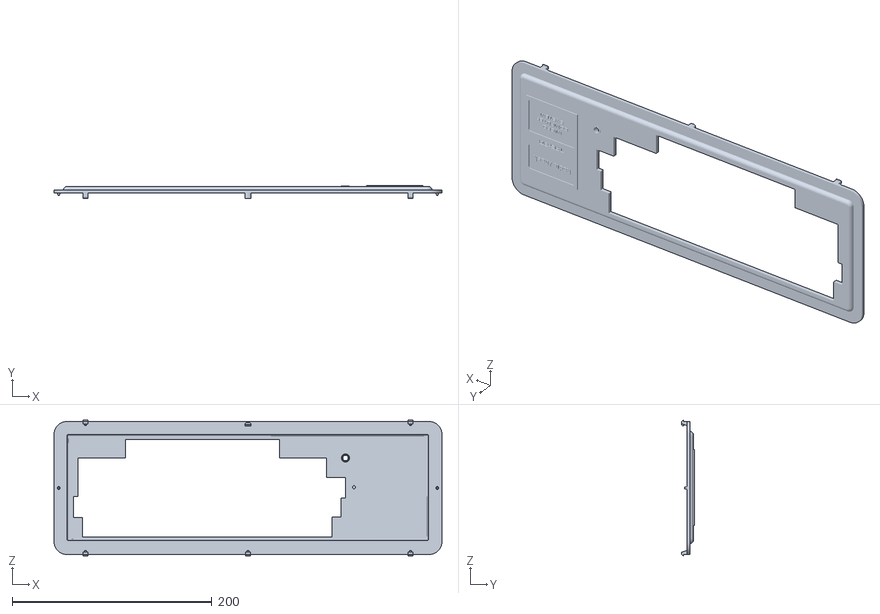
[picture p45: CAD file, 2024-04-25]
Keyboard_Bezel/Bezel_Alpha_Original.stl
388.0 x 13.0 x 135.5

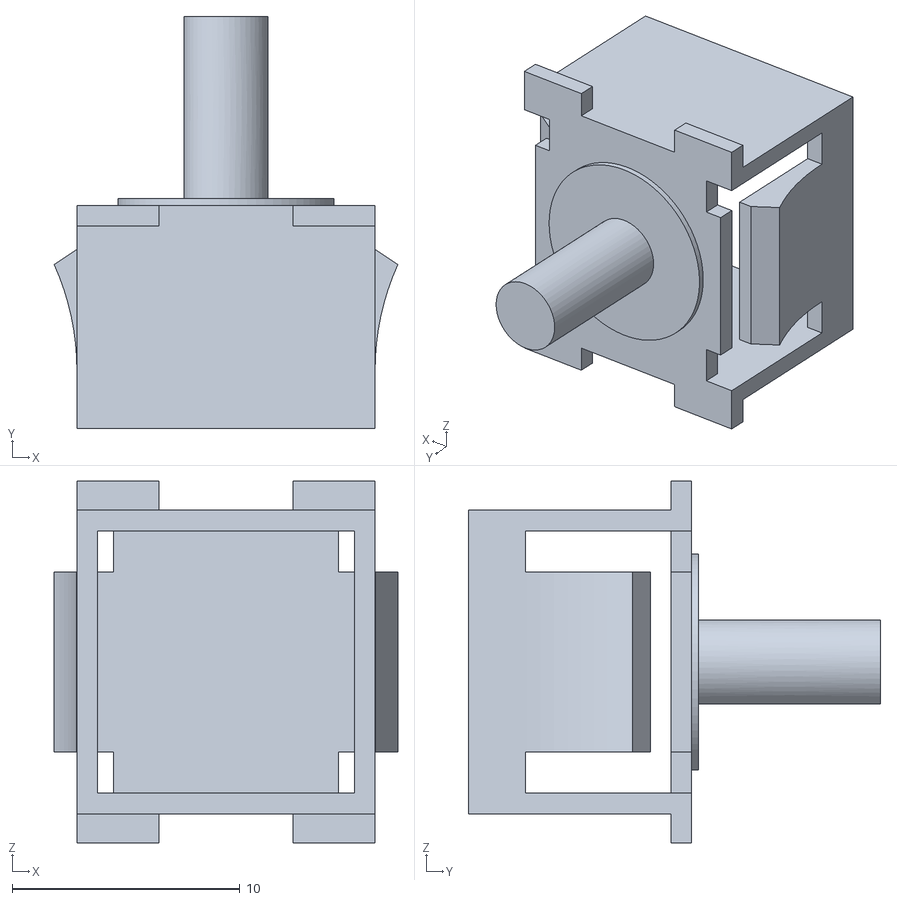
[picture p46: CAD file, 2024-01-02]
Keyboard_Button_Placeholder/Keyboard_Button_Placeholder.stl
15.1 x 18.1 x 15.9

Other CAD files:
Extension_Interface_Cover/Medium/Extension_Interface_Cover_Medium_Printable.stl
Keyboard_Clip/Keyboard_Clip.stl
Keyboard_Spacebar_Clip/Keyboard_Spacebar_Clip_Printable.stl
Keyboard_Stem_ALPS/Keyboard_Stem_ALPS.stl
Keyboard_Clip/Keyboard_Clip_Printable.stl
Keyboard_Spacebar_Clip/Keyboard_Spacebar_Clip.stl
Keyboard_Stem_ALPS/Keyboard_Stem_ALPS_Printable.stl
Main_Enclosure/Bottom_Left.stl
Main_Enclosure/Bottom_Left_Foot.stl
Main_Enclosure/Bottom_Mini.stl
Main_Enclosure/Bottom_Right.stl
Main_Enclosure/Bottom_Right_Foot.stl
Main_Enclosure/Improved_Bottom.stl
Main_Enclosure/Improved_Top.stl
Main_Enclosure/Original_Bottom.stl
Main_Enclosure/Original_Top.stl
Main_Enclosure/Top_Left.stl
Main_Enclosure/Top_Right.stl

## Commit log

2024-01-22 Various changes to parts
    [Keyboard_Shield2.stl, Keyboard_Spacebar_Clip.stl, Keyboard_Spacebar_Clip_Printable.stl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]
2024-03-11 Add sheet metal keyboard shield
    [Keyboard_Clip_Dual.stl, Keyboard_Shield_ALPS_v1.step, Keyboard_Spacebar_Clip_Dual.stl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]
2024-04-14 Updating ALPS shield
    [Keyboard_Shield.stl, Keyboard_Shield2.stl, Keyboard_Shield_ALPS_v1.step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]
2024-04-25 Adding order instructions and. Bezel
    [Bezel_Alpha_Original.stl, Bezel_NumPad_Original.stl]
2024-05-20 Main enclosure and licenses
    [Improved_Bottom.stl, Improved_Top.stl, Original_Bottom.stl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]
2024-05-24 Split Model 1
    [Bottom_Left.stl, Bottom_Left_Foot.stl, Bottom_Right.stl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]
2024-08-23 Add mini STLs
    [Bottom_Mini.stl, Top_Mini.stl]
